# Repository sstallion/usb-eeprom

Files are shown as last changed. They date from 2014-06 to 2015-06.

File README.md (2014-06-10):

# 28Cxxx EEPROM Programmer

This repository contains the firmware and hardware design for a PIC18F-based
USB programmer for the 28Cxxx series of parallel EEPROMs. The firmware and
hardware design are licensed under the Simplified BSD License with some
additional restrictions; see `LICENSE` and `LICENSE-MLA` for more detail.

This project meets the requirements of the OSHW Definition. CadSoft EAGLE
design files and an example bill of materials can be found in the `eagle`
subdirectory. For those without access to EAGLE, a PDF of the schematic and
board layout is provided.

PCBs may be ordered from [OSH Park](http://oshpark.com/shared_projects/PVCsM6xC).

Fully assembled and tested units may be purchased from
[Tindie](https://www.tindie.com/products/sstallion/28cxxx-eeprom-programmer).

## Firmware

The firmware requires the Microchip MPLAB XC8 compiler and the MPLAB X IPE
(Integrated Programming Environment) be installed and added to the user's PATH.

To build the firmware, issue:

    $ make all

To program the firmware using an attached MPLAB PICkit 3, issue:

    $ make run

Other programmers may be used; see `Makefile` for more detail.

## Usage

A cross-platform command line tool was developed to drive the programmer,
written in Go. Installing the `eeprom` tool requires Go 1.2 and libusb 1.0; see
[Getting Started](http://golang.org/doc/install) for more detail.

To install the `eeprom` tool, issue:

    $ go get github.com/sstallion/go/cmd/eeprom

Once installed, issue `eeprom help` for more detail about its usage.

## Compatibility

All 5V single supply chips are supported for read and write operations.
Extended functionality, such as page writes and chip erase are supported for
Atmel AT28C and compatible families.

_High-voltage programming is not supported._

## Support

Issues should be reported on [GitHub](https://github.com/sstallion/usb-eeprom/issues).
A [wiki](https://github.com/sstallion/usb-eeprom/wiki) is also maintained,
which contains additional documentation.

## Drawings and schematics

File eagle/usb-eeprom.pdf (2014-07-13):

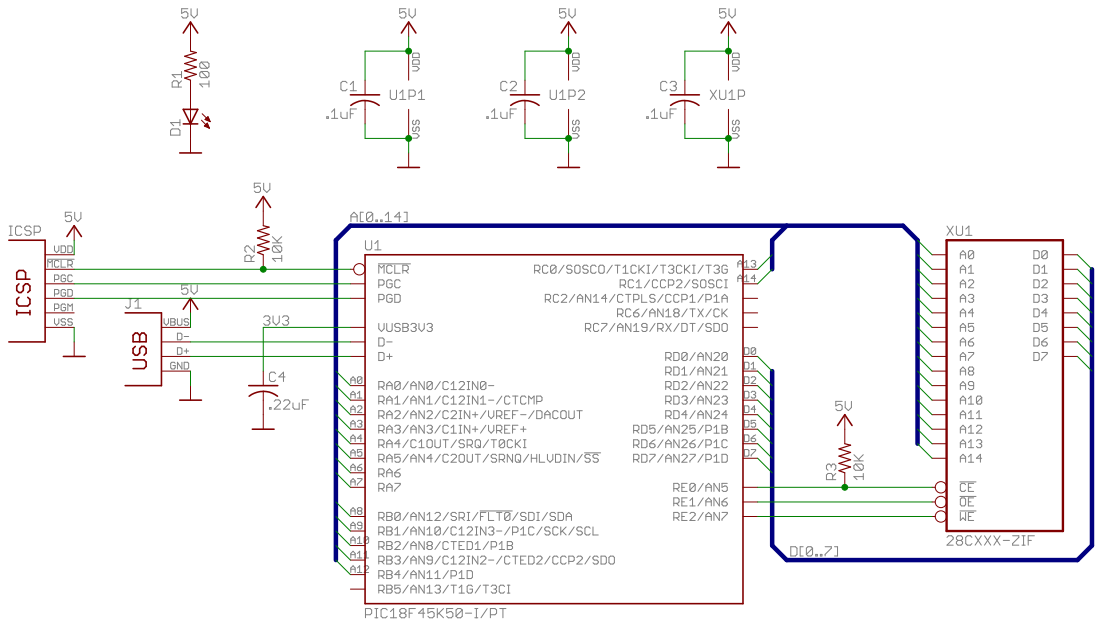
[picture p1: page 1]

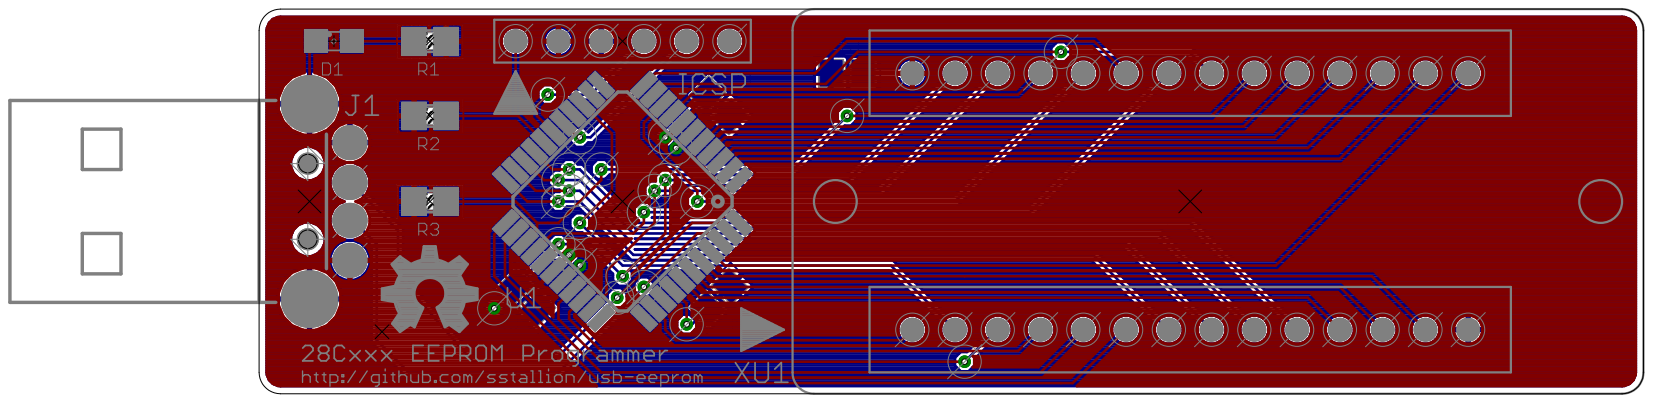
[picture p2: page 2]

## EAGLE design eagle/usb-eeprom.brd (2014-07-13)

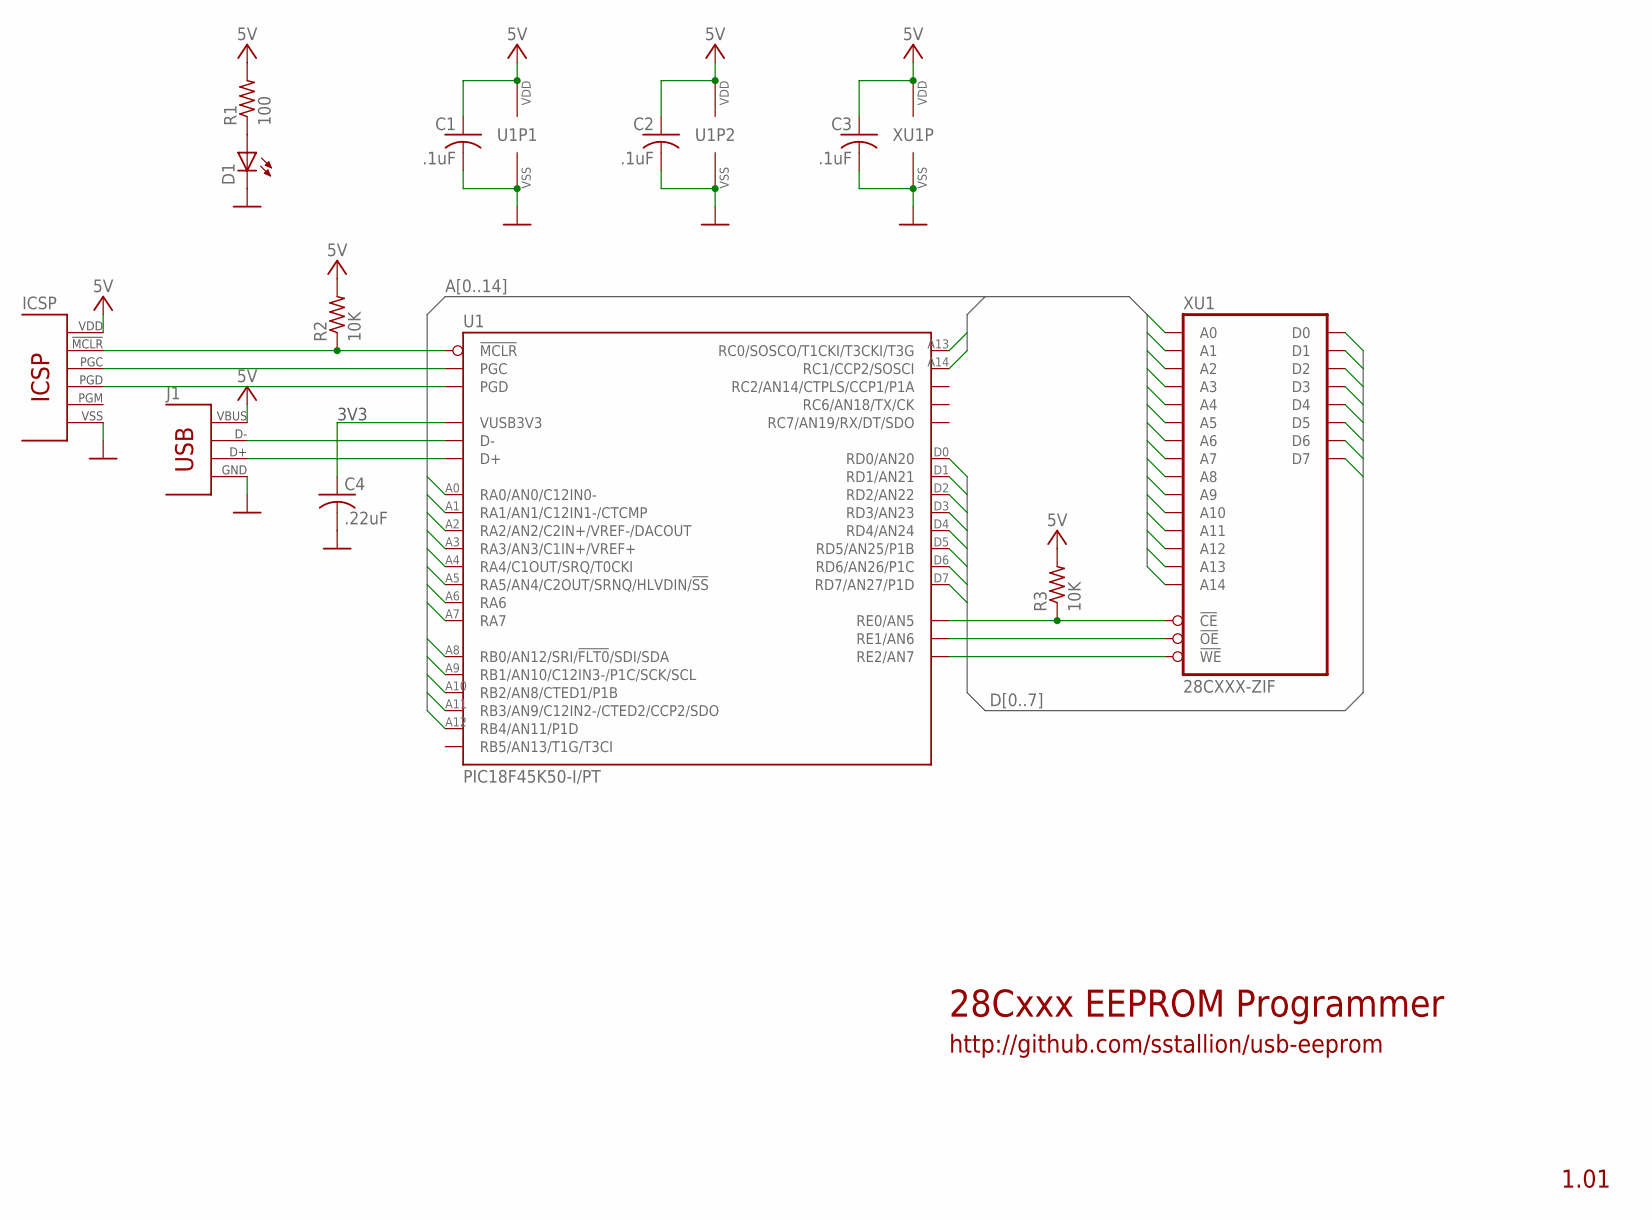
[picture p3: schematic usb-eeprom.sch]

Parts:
C1, C2, C3: .1uF; C0805; MFG_PN VJ0805Y104KXJCW1BC; MOUSER_PN 77-VJ0805Y104KXJCBC
C4: .22uF; C0805; MFG_PN VJ0805Y224KXJTW1BC; MOUSER_PN 77-VJ0805Y224KXJTBC
D1: BLUE; SML0805; MFG_PN APT2012QBC/D; MOUSER_PN 604-APT2012QBC/D
ICSP: ICSP
J1: USBA; MFG_PN 48037-0001; MOUSER_PN 538-48037-0001
R1: 100; R0805; MFG_PN CRCW0805100RFKEA; MOUSER_PN 71-CRCW0805-100-E3
R2, R3: 10K; R0805; MFG_PN CRCW080510K0FKEB; MOUSER_PN 71-CRCW080510K0FKEB
U1: PIC18F45K50-I/PT; TQFP44; MFG_PN PIC18F45K50-I/PT; MOUSER_PN 579-PIC18F45K50-I/PT
XU1: 28CXXX-ZIF; ZIF28; MFG_PN 228-1371-00-0602J; MOUSER_PN 517-228-1371-00

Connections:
+5V: C1.1, C2.1, C3.1, ICSP.2 (VDD), J1.1, R1.2, R2.2, R3.2, U1.7 (VDD), U1.28 (VDD), XU1.28 (VDD)
A0: U1.19 (RA0/AN0/C12IN0-), XU1.10 (A0)
A1: U1.20 (RA1/AN1/C12IN1-/CTCMP), XU1.9 (A1)
A2: U1.21 (RA2/AN2/C2IN+/VREF-/DACOUT), XU1.8 (A2)
A3: U1.22 (RA3/AN3/C1IN+/VREF+), XU1.7 (A3)
A4: U1.23 (RA4/C1OUT/SRQ/T0CKI), XU1.6 (A4)
A5: U1.24 (RA5/AN4/C2OUT/SRNQ/HLVDIN/!SS!), XU1.5 (A5)
A6: U1.31 (RA6), XU1.4 (A6)
A7: U1.30 (RA7), XU1.3 (A7)
A8: U1.8 (RB0/AN12/SRI/!FLT0!/SDI/SDA), XU1.25 (A8)
A9: U1.9 (RB1/AN10/C12IN3-/P1C/SCK/SCL), XU1.24 (A9)
A10: U1.10 (RB2/AN8/CTED1/P1B), XU1.21 (A10)
A11: U1.11 (RB3/AN9/C12IN2-/CTED2/CCP2/SDO), XU1.23 (A11)
A12: U1.14 (RB4/AN11/P1D), XU1.2 (A12)
A13: U1.32 (RC0/SOSCO/T1CKI/T3CKI/T3G), XU1.26 (A13)
A14: U1.35 (RC1/CCP2/SOSCI), XU1.1 (A14)
D0: U1.38 (RD0/AN20), XU1.11 (D0)
D1: U1.39 (RD1/AN21), XU1.12 (D1)
D2: U1.40 (RD2/AN22), XU1.13 (D2)
D3: U1.41 (RD3/AN23), XU1.15 (D3)
D4: U1.2 (RD4/AN24), XU1.16 (D4)
D5: U1.3 (RD5/AN25/P1B), XU1.17 (D5)
D6: U1.4 (RD6/AN26/P1C), XU1.18 (D6)
D7: U1.5 (RD7/AN27/P1D), XU1.19 (D7)
GND: C1.2, C2.2, C3.2, C4.2, D1.C, ICSP.3 (VSS), J1.4, J1.5 (4), J1.6 (4), U1.6 (VSS), U1.29 (VSS), XU1.14 (VSS)
unnamed: ICSP.1 (!MCLR), R2.1, U1.18 (!MCLR)
unnamed: ICSP.5 (PGC), U1.16 (PGC)
unnamed: ICSP.4 (PGD), U1.17 (PGD)
unnamed: C4.1, U1.37 (VUSB3V3)
unnamed: R3.1, U1.25 (RE0/AN5), XU1.20 (!CE)
unnamed: J1.2, U1.42 (D-)
unnamed: J1.3, U1.43 (D+)
unnamed: U1.26 (RE1/AN6), XU1.22 (!OE)
unnamed: U1.27 (RE2/AN7), XU1.27 (!WE)
unnamed: D1.A, R1.1

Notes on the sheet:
28Cxxx EEPROM Programmer
http://github.com/sstallion/usb-eeprom
3V3

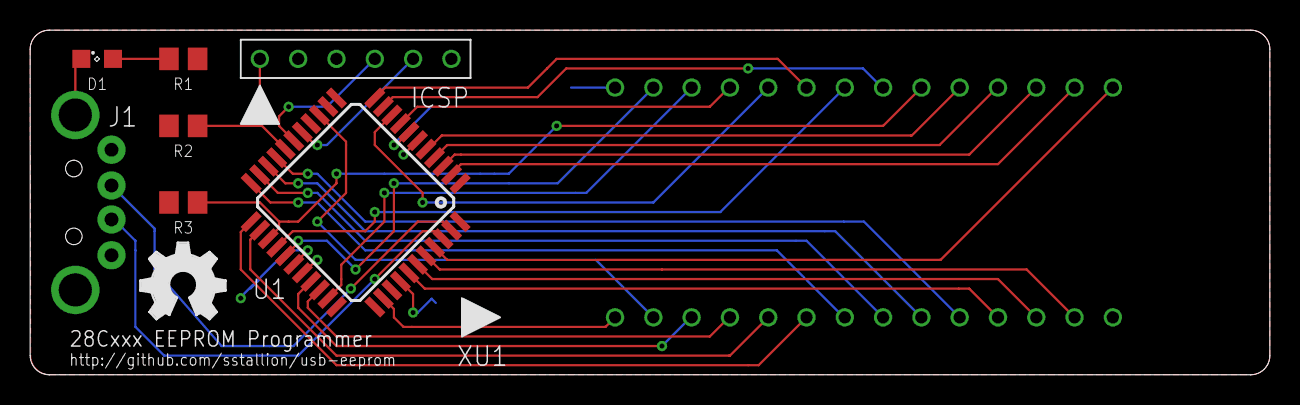
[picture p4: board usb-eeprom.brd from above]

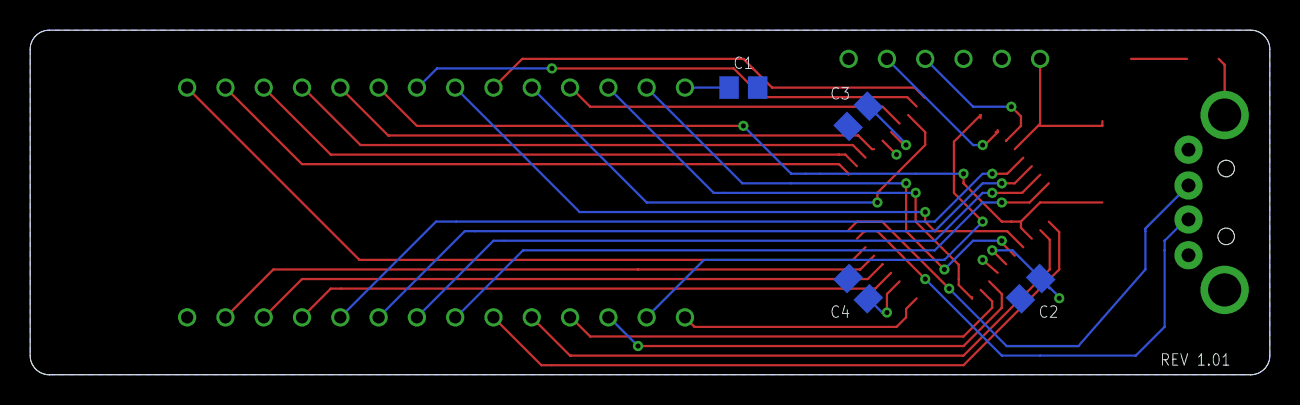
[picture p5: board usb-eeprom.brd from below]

Board: 2 copper layers, 82.2 x 22.9 mm, 13 parts (4 on the bottom side), 35 nets.

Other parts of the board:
LOGO: OSHW

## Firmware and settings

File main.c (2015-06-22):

/*
 * Copyright (c) 2015 Steven Stallion
 * All rights reserved.
 *
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
 * THIS SOFTWARE IS PROVIDED BY THE AUTHOR AND CONTRIBUTORS ``AS IS'' AND
 * ANY EXPRESS OR IMPLIED WARRANTIES, INCLUDING, BUT NOT LIMITED TO, THE
 * IMPLIED WARRANTIES OF MERCHANTABILITY AND FITNESS FOR A PARTICULAR PURPOSE
 * ARE DISCLAIMED.  IN NO EVENT SHALL THE AUTHOR OR CONTRIBUTORS BE LIABLE
 * FOR ANY DIRECT, INDIRECT, INCIDENTAL, SPECIAL, EXEMPLARY, OR CONSEQUENTIAL
 * DAMAGES (INCLUDING, BUT NOT LIMITED TO, PROCUREMENT OF SUBSTITUTE GOODS
 * OR SERVICES; LOSS OF USE, DATA, OR PROFITS; OR BUSINESS INTERRUPTION)
 * HOWEVER CAUSED AND ON ANY THEORY OF LIABILITY, WHETHER IN CONTRACT, STRICT
 * LIABILITY, OR TORT (INCLUDING NEGLIGENCE OR OTHERWISE) ARISING IN ANY WAY
 * OUT OF THE USE OF THIS SOFTWARE, EVEN IF ADVISED OF THE POSSIBILITY OF
 * SUCH DAMAGE.
 */

#include <xc.h>
#include <stdbool.h>
#include <stdint.h>

#include "config.h"
#include "usb.h"
#include "usb_device.h"
#include "usb_device_generic.h"

#define MAX(x, y) ((x) > (y) ? (x) : (y))
#define MIN(x, y) ((x) < (y) ? (x) : (y))

#define NELEM(x) (sizeof (x) / sizeof *(x))

#define ADDRA(x) ((x) & 0xFF)
#define ADDRB(x) ((x)>>8 & 0x1F)
#define ADDRC(x) ((x)>>13 & 0x3)

#define nCE (1<<0)	/* Chip Enable */
#define nOE (1<<1)	/* Output Enable */
#define nWE (1<<2)	/* Write Enable */

uint8_t in[USBGEN_EP_SIZE] @0x500;
uint8_t out[USBGEN_EP_SIZE] @0x540;

enum {
	STATE_CMD,
	STATE_DATA,
	STATE_STATUS,
} state;

void
ClockInit(void)
{
	/*
	 * Configure the system clock to run at 48MHz via the high-frequency
	 * internal oscillator. This provides sufficient performance and
	 * stability without requiring an external clock source.
	 */
	OSCTUNE = SPLLMULT;	/* 3xPLL */
	OSCCON = 0x70;		/* HFINTOSC (16MHz) */
	OSCCON2 = PLLEN;	/* PLL Enable */

	/* Wait for system clock to settle */
	while (!(OSCCON2 & PLLRDY))
		;

	/* Enable Active Clock Tuning for USB */
	ACTCON = ACTEN | ACTSRC;
}

void
EEPROMInit(void)
{
	/*
	 * Drive outputs low, except for !OE and !WE. A pull-up resistor on !CE
	 * ensures the chip remains disabled until the corresponding output
	 * driver is enabled.
	 */
	LATA = 0;
	LATB = 0;
	LATC = 0;
	LATD = 0;
	LATE = nOE | nWE;

	/* Disable analog inputs */
	ANSELA = 0;
	ANSELB = 0;
	ANSELC = 0;
	ANSELD = 0;
	ANSELE = 0;

	/* Enable output drivers */
	TRISA = 0;
	TRISB = 0;
	TRISC = 0;
	TRISD = 0;
	TRISE = 0;

	/*
	 * Some chips (notably the AT28C and CAT28C families) employ a power on
	 * delay to protect against inadvertent writes.
	 */
	__delay_ms(10);
}

void
EEPROMPoll(uint8_t data)
{
	TRISD = ~0;
	LATE = nWE;
	while (PORTD != data)
		;
	LATE = nOE | nWE;
}

void
EEPROMRead(uint16_t addr, uint8_t *buf, uint16_t len)
{
	TRISD = ~0;
	do {
		LATC = ADDRC(addr);
		LATB = ADDRB(addr);
		LATA = ADDRA(addr);
		LATE = nWE;
		*buf++ = PORTD;
		LATE = nOE | nWE;
	} while (++addr, --len);
}

void
EEPROMWrite(uint16_t addr, uint8_t *buf, uint16_t len)
{
	do {
		TRISD = 0;
		LATC = ADDRC(addr);
		LATB = ADDRB(addr);
		LATA = ADDRA(addr);
		LATD = *buf++;
		LATE = nOE;
		LATE = nOE | nWE;
		EEPROMPoll(buf[-1]);
	} while (++addr, --len);
}

void
EEPROMWritePage(uint16_t addr, uint8_t *buf, uint16_t len)
{
	TRISD = 0;
	LATC = ADDRC(addr);
	LATB = ADDRB(addr);
	do {
		LATA = ADDRA(addr);
		LATD = *buf++;
		LATE = nOE;
		LATE = nOE | nWE;
	} while (++addr, --len);
	EEPROMPoll(buf[-1]);
}

void
EEPROMErase(void)
{
	static uint16_t addr[] = {
		0x5555, 0x2AAA, 0x5555, 0x5555, 0x2AAA, 0x5555,
	};
	static uint8_t data[] = {
		0xAA, 0x55, 0x80, 0xAA, 0x55, 0x10,
	};

	TRISD = 0;
	for (uint8_t i = 0; i < NELEM(addr); ++i) {
		LATC = ADDRC(addr[i]);
		LATB = ADDRB(addr[i]);
		LATA = ADDRA(addr[i]);
		LATD = data[i];
		LATE = nOE;
		LATE = nOE | nWE;
	}
	__delay_ms(10);
	__delay_ms(10);
}

bool
USBEventHandler(USB_EVENT event, void *pdata, uint16_t size)
{
	switch (event) {
	case EVENT_CONFIGURED:
		USBEnableEndpoint(USBGEN_EP_NUM, USB_HANDSHAKE_ENABLED |
		    USB_OUT_ENABLED | USB_IN_ENABLED | USB_DISALLOW_SETUP);
		state = STATE_CMD;
		break;

	case EVENT_EP0_REQUEST:
		USBCheckVendorRequest();
		break;

	case EVENT_RESET:
		if (USBGetDeviceState() == CONFIGURED_STATE) {
			RESET();
		}
		break;
	}
	return true;
}

void interrupt
Interrupt(void)
{
	USBDeviceTasks();
}

void
main(void)
{
	USB_HANDLE h;
	uint8_t cmd;
	uint16_t addr, n;
	uint24_t len;

	ClockInit();
	EEPROMInit();
	USBDeviceInit();
	USBDeviceAttach();

	for (;;) {
		if (USBGetDeviceState() < CONFIGURED_STATE ||
		    USBIsDeviceSuspended())
			continue;

		switch (state) {
		case STATE_CMD:
			h = USBGenRead(USBGEN_EP_NUM, out, sizeof out);
			while (USBHandleBusy(h))
				;
			switch (cmd = *out) {
			case 'R': /* Read */
			case 'W': /* Byte Write */
			case 'P': /* Page Write */
				memcpy(&addr, out+1, sizeof addr);
				memcpy(&n, out+3, sizeof n);
				len = (uint24_t)n + 1;
				state = STATE_DATA;
				break;
			case 'Z': /* Chip Erase */
				addr = 0;
				len = 0;
				EEPROMErase();
				state = STATE_STATUS;
				break;
			}
			break;

		case STATE_DATA:
			switch (cmd) {
			case 'R': /* Read */
				n = MIN(len, sizeof in);
				EEPROMRead(addr, in, n);
				h = USBGenWrite(USBGEN_EP_NUM, in, n);
				while (USBHandleBusy(h))
					;
				break;
			case 'W': /* Byte Write */
			case 'P': /* Page Write */
				h = USBGenRead(USBGEN_EP_NUM, out, sizeof out);
				while (USBHandleBusy(h))
					;
				n = USBHandleGetLength(h);
				if (cmd == 'W')
					EEPROMWrite(addr, out, n);
				else
					EEPROMWritePage(addr, out, n);
				break;
			}
			addr += n;
			len -= n;
			if (len == 0)
				state = STATE_STATUS;
			break;

		case STATE_STATUS:
			memcpy(in, &addr, sizeof addr);
			h = USBGenWrite(USBGEN_EP_NUM, in, sizeof addr);
			while (USBHandleBusy(h))
				;
			state = STATE_CMD;
			break;
		}
	}
}

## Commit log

2014-05-15 Initialize EAGLE project
    [usb-eeprom.brd, usb-eeprom.sch]
2014-05-15 Update DEVICE/PROGRAMMER
2014-05-15 Add PIC18(L)F45K50 symbol
    [usb-eeprom.brd, usb-eeprom.sch]
2014-05-17 Update schematic; generate BOM
    [usb-eeprom.brd, usb-eeprom.sch]
2014-05-20 Initial PCB layout
    [usb-eeprom.brd, usb-eeprom.sch]
2014-05-20 Update to official PID
2014-05-20 Add usb-eeprom-board.pdf
2014-05-23 Fix page addressing; disable WDT
    [main.c]
2014-05-23 Update BOM
2014-05-23 Fix broken addressing (really)
    [main.c]
2014-05-24 Replace D1 with SML0805 package
    [usb-eeprom.brd, usb-eeprom.sch]
2014-06-03 Cosmetic fixes; REV 1.01 layout
    [usb-eeprom.brd, usb-eeprom.sch]
2014-06-10 Update documentation
    [usb-eeprom.brd, usb-eeprom.sch]
2014-07-13 Upgrade to EAGLE v6.6; update formatting
    [usb-eeprom.brd, usb-eeprom.sch]
2015-06-22 Correct bad addr assignment in Chip Erase
    [main.c]
